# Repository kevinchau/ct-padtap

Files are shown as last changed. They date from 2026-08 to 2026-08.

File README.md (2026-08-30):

# PadTap

Y-harness + board that steals 48 V from the Cybertruck **wireless charger** to run a **Starlink Mini**, without unplugging the pad.

The charger and the key-card reader are the same module. A 1:1 pass-through keeps NFC, HVAC LIN, and USB alive. The board listens to the on-screen pad toggle (LIN) and switches a 5.5 mm barrel.

This is **not** a Tesla-approved tap. Approved 48 V points are the roof and frunk (400 W). Read [SAFETY.md](SAFETY.md) first.

System

Direct 48 V: Mini sees the Tesla rail (typically 44–50 V). The FET opens at **56.0 V** so Tesla’s 58 V peak never reaches the barrel. Digital fuses trip on **inrush** — **10 Ω NTC** on VIN and an **80 ms FET ramp**. Do not skip the thermistor.

The old 36 V buck build is **deprecated**. It does not fit the 15 mm sled. Archive: [hardware/schematic.md](hardware/schematic.md).

## Connector

C X0648 · Tesla **1042593-03-A**. Wire-to-board, not a 4-pin.

| Side | Part |
| --- | --- |
| Vehicle plug | Sumitomo **6098-5718** grey 12-way female |
| Charger | Sumitomo **6098-6210** DL PCB header |

Y: vehicle 5718 → our 6210 (solder a pigtail, pot it) → 1:1 → our 5718 → charger 6210.

Cavity map

Y-harness

| Pin | Color | Terminal | |
| --- | --- | --- | --- |
| **1** | RD/BU 1.00 | 8240-0213 | 48 V HSD — tap |
| 3 | WH/BU 1.00 | 8240-0213 | USB GND thru — no tap |
| **4** | GN 0.35 | 8240-0215 | LIN in — listen only |
| **9** | BN/BU 1.00 | 8240-0213 | WPC GND — tap |
| 10 | GY 0.35 | 8240-0215 | LIN out to HVAC — **never break** |
| 11 / 12 | PK/WH, BU/WH 0.35 | 8240-0215 | CAN auth — no tap |

Latch up, cavities **1–6 over 7–12**. Empty: 2, 5–8. Crimp **18 AWG** into 0213 (16 AWG is out of spec). Full rules: [hardware/harness.md](hardware/harness.md).

## Board

Direct 48 V (`pio run -e direct`):

Direct schematic

- ESP32-C3 SuperMini, TLIN2029 **RX only** (TX not wired)
- IRL540NPBF 100 V FET, low-side on the barrel sleeve
- LM393 + TL431 OVLO, trips **56.14 V** · VIN sense **215 k / 10 k** into GPIO4 (56 V → 2.49 V)
- Gate: 1 k from GPIO5, 10 k pulldown, 47 k + 1 µF smooth the ramp PWM, 1N4148 for fast turn-off
- Littelfuse **0997003.WXN** MINI 3 A **58 V** in and out — not a 32 V blade
- NTC + 80 ms ramp on the harness, outside the box

```
cd firmware/padtap
pio run -e direct -t upload
pio device monitor -b 115200
```

`mode a` / `b` / `c` / `auto` · `ov reset`

| Mode | |
| --- | --- |
| AUTO | First toggle: latch A if 48 V drops, B if LIN flips |
| A | Follow 48 V |
| B | Follow LIN (expected) |
| C | On whenever the rail is up |

OVLO wins: VIN ≥ 56.0 V → FET off.

## PCB — Rev A.1

**58 × 34 mm**, 2-layer. USB-C on the south window, barrel on the east hole, J1 on the west comb.

PadTap Rev A.1

| Zone | |
| --- | --- |
| West | 48 V island: TVS + Schottky + 10 µF/100 V. 1.6 mm rail to the barrel along the south edge, not under the MCU |
| Buck | XL7015, short SW node, catch diode on that pin only |
| North | OVLO (LM393 + TL431), away from SW |
| LIN | 1 k + 220 pF + PESD. TXD **10 k to 5 V** (internal pulldown would dominate the bus) |
| East | IRLR3110 DPAK, 9 thermal vias on the tab |

Gerbers: [hardware/pcb/reva/PadTap-RevA-gerbers.zip](hardware/pcb/reva/PadTap-RevA-gerbers.zip). Fuses and NTC stay on the harness. Confirm XL7015 pinout before SMT.

## Case

**64 × 40 × 15 mm** PETG, sized to the 58 × 34 mm board. VHB the lid under a console panel. Comb west (at J1), barrel east, USB-C south. Print [hardware/enclosure](hardware/enclosure). Confirm **15 mm** of clearance.

Section

## Buy and install

Order list with links: **[hardware/shop.md](hardware/shop.md)**.

T20 at **5 N·m**. Meter the official Mini PSU: barrel is 5.5 mm, **center +**. First wake without Starlink — key card and Qi must still work — then plug the Mini.

| | |
| --- | --- |
| [hardware/shop.md](hardware/shop.md) | Housings, terminals, 58 V fuses, tools |
| [hardware/harness.md](hardware/harness.md) | Pin rules |
| [hardware/pcb/reva](hardware/pcb/reva) | Rev A Gerbers, BOM, CPL |
| [firmware/padtap](firmware/padtap) | ESP32-C3 |

MIT. 48 V is live. That is on you.

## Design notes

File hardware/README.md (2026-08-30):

# Hardware

See [../README.md](../README.md) for the full design. Drawings: [../docs/diagrams/](../docs/diagrams/).

| Path | What |
| --- | --- |
| `harness.md` | Y-harness, connector hunt, pass-through rules |
| `schematic-direct.md` | **Direct 48 V** — the build |
| `schematic.md` | Deprecated 36 V buck archive |
| `bom.csv` | Order list (`rev` = all / direct). `buck` rows are deprecated |
| `pcb/reva/` | **Rev A.1** 58×34 mm Gerbers, JLCPCB BOM/CPL |

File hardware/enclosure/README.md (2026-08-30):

# Under-panel sled

Two-piece PETG, **64 × 40 × 15 mm**, sized to the Rev A.1 board (58 × 34 mm). VHB the lid to the underside of a console panel.

Print `padtap_case.scad` if you have OpenSCAD. `generate_stl.py` emits compact ASCII STLs with the same openings.

| File | |
| --- | --- |
| `padtap_case.scad` | Source. `PART="base"` / `"lid"` / `"preview"` |
| `padtap_base.stl` | Body, openings, bosses |
| `padtap_lid.stl` | Mount face (print this side on the bed) |

## Openings

| Face | Feature | Size |
| --- | --- | --- |
| West | Cable comb, 3 U-slots | 4.0 mm, lines up with J1 VIN / GND / LIN |
| East | Barrel | Ø 8.2 mm at board y = 22.5, center 6 mm above floor |
| South | USB-C | 9.6 × 3.6 mm, centred on board x = 30 |
| Lid | LED membranes | 2× Ø 2.8 mm over the 0805s |
| Lid, bed face | VHB pockets | 4× 10 mm square |

Bosses match the PCB holes at (3, 3), (55, 3), (3, 31), (55, 31).

## Height

Assembled drop **15 mm**. Internal 12.1 mm — enough for the DPAK FET, ESP32-C3-MINI-1, and XL7015. Direct 48 V only.

Fuses and the 10 Ω NTC stay on the harness.

## Print

- PETG. Not PLA.
- 0.2 mm layers, 4 perimeters, 30 % gyroid, 250 / 80 °C.
- Base: floor down. No supports.
- Lid: **VHB face on the bed**, lip up.
- 4× M2.5 × 6 mm into heat-set inserts.

Confirm 15 mm of clearance under the panel before you glue.

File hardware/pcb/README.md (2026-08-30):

# PCB

[**Rev A.1 — Direct 48 V**](reva/) — **58 × 34 mm**, 2-layer.

- [`reva/PadTap-RevA-gerbers.zip`](reva/PadTap-RevA-gerbers.zip) → JLCPCB
- [`reva/pcb-top.svg`](reva/pcb-top.svg)
- `python3 reva/generate.py` regenerates

Sits on the sled floor against the south wall. J1 at the comb. Fuses and NTC are not on this board.

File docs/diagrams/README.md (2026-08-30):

# Drawings

SVGs for the README. No concept photos.

```
python3 generate.py
```

| File | |
| --- | --- |
| `system-direct.svg` | Block diagram |
| `schematic-direct.svg` | Controller |
| `pin-map.svg` | X0648 cavity map, latch up |
| `harness.svg` | Vehicle 5718 → 6210 → 5718 → charger |
| `mating.svg` | 5718 onto 6210 |
| `ovlo.svg` | 56.14 V trip |
| `enclosure-iso.svg` / `enclosure-section.svg` / `enclosure-pack-*.svg` | 64 × 40 × 15 mm sled |
| `pcb-top.svg` | Rev A.1 board, 58 × 34 mm |

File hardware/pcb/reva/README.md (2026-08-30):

# PadTap Direct 48 V — Rev A.1

**58 × 34 mm**, 2-layer, 1.6 mm FR4. ~45 % of the sled cavity. Sits on the floor against the south wall.

Top

| | |
| --- | --- |
| West | J1 VIN / GND / LIN — 18 AWG, ~40 mm pigtail to the comb |
| East | J2 barrel through the sled hole, center + |
| South | USB-C through the window |
| 48 V | West island: TVS + Schottky + 10 µF/100 V. 1.6 mm rail to the barrel along the **south**, not under the MCU |
| SW | XL7015 pin 2 to L1, catch diode on that node only |
| OVLO | North, away from SW. LM393 OC on nGATE |
| Q1 | IRLR3110 DPAK, 9 thermal vias on the tab, source to GND pour |
| LIN | 1 k series + 220 pF + PESD. TXD **10 k to 5 V** (internal pulldown would dominate the bus). RXD 4.7 k to 3V3 |

Fuses and the NTC stay on the harness.

## Order

[`PadTap-RevA-gerbers.zip`](PadTap-RevA-gerbers.zip) → JLCPCB, 2-layer, 1.6 mm, black, HASL. SMT optional: `bom-jlc.csv` + `cpl-jlc.csv`. Confirm LCSC C-numbers.

Place the board so USB-C (30 mm from the west edge) lines up with the 9.6 mm window (outer x = 72).

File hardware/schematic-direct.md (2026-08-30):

# PadTap Direct 48 V

Switched pass-through. No 36 V buck. Starlink Mini sees the Cybertruck rail (typically 44–50 V).

Tesla’s published accessory range is **28 V min / 44–50 V nominal / 58 V max**. Mini is printed **12–48 V**, but the input stage is a 48 V-class converter: Infineon **BSZ146N10LS5** 100 V FETs and a **60 V TVS** across the barrel (clamps ~66–73 V). That hardware will take **~56 V**. Tesla’s 58 V peak is the gap — we disconnect at **56.0 V** instead of converting.

Double-converting (our buck, then Mini’s buck) wastes 4–8 W at cruise. Direct FET loss at 40 W / 48 V is ~0.2 W.

```
VIN_48 ── MINI 3 A 58 V ── NTC 10 Ω ── Schottky SS510 ──┬── SMBJ58A ── GND
                                      │
                                      ├── 5 V buck (7–60 V) ── ESP32-C3 + TLIN2029 VSUP
                                      │
                                      ├── 215 k / 10 k ── ADC GPIO4 + 3.3 V zener
                                      │         │
                                      │         └── 215 k / 10 k ── LM393 IN−
                                      │                              IN+ = 2.495 V (TL431)
                                      │                              OC output ── FET gate
                                      │
                                      └── F2 3 A ── barrel center +
                                                    barrel sleeve ── Q1 drain (IRL540NPBF, 100 V)
                                                                     Q1 source ── GND
                                                                     Q1 gate ← GPIO5 + LM393 OC
```

Low-side switch on the Mini return, same as the 36 V build. Do **not** low-side the WPC ground.

Tesla 48 V **digital fuses** trip on capacitor inrush. The NTC (VIN, on the harness) is what stops a buck from killing the channel — same as a frunk 48 V tap. The 80 ms FET ramp is what stops Mini’s input caps from doing it when the pad toggle arms the output. The NTC is already warm by then (ESP32 is up) so it cannot save Mini turn-on.

## Why 56.0 V, not 58 V

| Limit | V | Source |
| --- | --- | --- |
| Mini printed max | 48 | Spec sheet next to the barrel |
| Mini hardware ceiling | ~56–60 | 100 V input FETs, 60 V TVS |
| Direct OVLO trip | **56.0** | LM393 + firmware latch |
| Direct OVLO clear | 54.0 | Hysteresis |
| Tesla accessory max | 58 | DIY 48 V power-feed document |

If the LV bus ever sits at 58 V, Direct turns Starlink off. That is rare (nominal 44–50 V).

Do **not** put a 54 V TVS across the barrel. Tesla is allowed to run at 50 V; a 54 V clamp would dump the truck’s rail into the diode. Disconnect, don’t clamp.

## OVLO (hardware)

LM393, 5 V VCC, open-collector to the FET gate.

- IN+ = TL431 2.495 V
- IN− = VIN × 10 k / (215 k + 10 k)
- Trip: 2.495 × 225 / 10 = **56.14 V** (215 k 1 %)
- When VIN > 56 V, OC conducts, gate = 0, FET off — even if the ESP32 is wedged
- 1 k between GPIO5 and the OC node so a fight is 3.3 mA, not 33 mA
- After the OC node: 47 k series + 1 µF gate–source smooth the 20 kHz ramp PWM into a gate ramp; 1N4148 across the 47 k dumps the gate fast when the OC (or GPIO) falls

Firmware is the second gate: latches `ov` at 56.0 V, clears at 54.0 V, serial `ov reset` to force. Its VSENSE divider is **215 k / 10 k** (same values as the comparator's) — a 100 k / 10 k divider would clip at the 3.3 V zener around 36 V and the firmware latch could never see 56 V.

## Nets

| Net | From | To |
| --- | --- | --- |
| VIN_48 | Y-harness 48 V+ via 3 A fuse | NTC 10 Ω → Schottky → SMBJ58A → 5 V buck + barrel center via F2 |
| GND | Y-harness GND | Board GND, Q1 source |
| LIN_BUS | Y-harness LIN (parallel) | TLIN2029 LIN pin |
| LIN_RX | TLIN2029 RXD | ESP32 GPIO20 |
| V5 | 5 V buck | ESP32 5V, TLIN VSUP, LM393 VCC, TL431 bias |
| VOUT+ | F2 3 A after VIN | Barrel center + (unswitched) |
| VOUT− | Barrel sleeve | Q1 drain (switched low-side) |
| VSENSE | 215 k / 10 k on VIN_48 (56 V → 2.49 V) | ESP32 ADC, 3.3 V zener backstop |
| nGATE | ESP32 GPIO5 + 1 k, 10 k pulldown, LM393 OC | 47 k + 1 µF RC → IRL540NPBF gate, 1N4148 across the 47 k for fast turn-off |

## GPIO

Same map as the 36 V build.

| Pin | Function |
| --- | --- |
| GPIO20 | UART RX (LIN) |
| GPIO5 | FET gate (1 k) |
| GPIO4 | ADC VIN_48 |
| GPIO6 | Amber LED, rail present |
| GPIO7 | Green LED, output armed |

## Protection

- Littelfuse **0997003.WXN** MINI 3 A **58 V** on VIN_48
- Same 3 A 58 V on barrel (Starlink 60 W / 48 V ≈ 1.25 A; 60 W / 28 V ≈ 2.1 A)
- SMBJ58A on VIN_48 only
- Series Schottky 100 V 5 A reverse protection
- 3.3 V zener on ADC node (backstop — the 215 k / 10 k divider stays under 2.6 V even at 58 V)
- LM393 OVLO + firmware latch at 56.0 V
- 100 V logic-level FET (**IRL540NPBF**) — FQP13N10L is obsolete; 60 V FQP30N06L is too close to Tesla max

## Current

| Mini load | @ 36 V (buck) | @ 48 V (direct) |
| --- | --- | --- |
| 25 W cruise | 0.69 A | 0.52 A |
| 40 W typical | 1.11 A | 0.83 A |
| 60 W peak | 1.67 A | 1.25 A |

3 A fuse still the right ceiling. Tap pigtails are **18 AWG GXL** into 8240-0213 (16 AWG is out of spec).

## Forbidden

| Don’t | Why |
| --- | --- |
| 36 V buck in this build | That’s the other schematic |
| FQP30N06L (60 V) | Tesla max 58 V + Mini input inductance |
| SMBJ40A / 54 V TVS on VOUT | Clamps a legal Tesla rail |
| LM2596 / MP1584 | 5 V buck must be 60 V-in |
| Driving LIN TX | Sniffer only |
| Feeding Mini above 56 V “because the TVS is 60 V” | TVS is a clamp, not an operating point |

Flash the `direct` PlatformIO env.

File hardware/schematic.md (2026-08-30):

# DEPRECATED — Buck 36 V

**Do not build this.** PadTap is Direct 48 V. The 64 × 40 × 15 mm sled cannot fit a 36 V module. Firmware `env:buck` is gone.

Use **[schematic-direct.md](schematic-direct.md)**.

The rest of this page is an archive of the old conservative path (60 V → 36 V module, Mini stays inside the printed 12–48 V rating).

---

# PadTap controller (archive)

Two builds, one Y-harness, one sled.

| | **Direct 48 V** (default) | **Buck 36 V** (conservative) |
| --- | --- | --- |
| Doc | [schematic-direct.md](schematic-direct.md) | this page |
| Mini sees | Raw Tesla rail, typically 44–50 V | Regulated 36.00 V |
| Extra conversion | None | 60 V → 36 V buck ≤ 12 mm |
| Overvoltage | LM393 + firmware kill FET at **56.0 V** | Buck absorbs Tesla’s 58 V peak |
| Use when | You want the efficiency; Mini hardware takes ~56 V | You want to stay inside the printed 12–48 V rating |

Shared front end: 48 V in (Tesla 28–58 V) → fused → **NTC 10 Ω ICL** → reverse Schottky → TVS.

Tesla 48 V digital fuses trip on buck input-cap inrush. The NTC is not optional on the 36 V build — that is the exact failure of a raw converter on the frunk tap. Direct still needs it for the 5 V MCU buck, plus an 80 ms FET ramp for Mini’s own caps.

- **5 V buck** (7–60 V in): ESP32-C3 + TLIN2029A-Q1 VSUP
- **LIN RX only** — TX pin not wired

## Buck 36 V

48 V in → fused → reverse Schottky → TVS → two bucks.

- **36 V buck** (8–60 V in, 3 A, ≤10 mm tall): Starlink Mini sweet spot. The 12.1 mm Direct sled does **not** fit a 12 mm tower — use a SIP or skip this build.
- **FQP30N06L** low-side switch on Starlink return (36 V, 60 V FET is enough here)

## Nets (buck)

| Net | From | To |
| --- | --- | --- |
| VIN_48 | Y-harness 48 V+ via 3 A fuse | NTC 10 Ω → Schottky → SMBJ58A → both bucks |
| GND | Y-harness GND | Board GND, FET source, barrel sleeve |
| LIN_BUS | Y-harness LIN (parallel) | TLIN2029 LIN pin |
| LIN_RX | TLIN2029 RXD | ESP32 GPIO20 |
| V5 | 5 V buck | ESP32 5V, TLIN VSUP |
| V36 | 36 V buck | Barrel center via FET + 3 A fuse |
| VSENSE | 215 k / 10 k on VIN_48 | ESP32 ADC, 3.3 V zener backstop |
| nGATE | ESP32 GPIO5 + 100 Ω | FET gate, 10 k pulldown |

## GPIO

| Pin | Function |
| --- | --- |
| GPIO20 | UART RX (LIN) |
| GPIO5 | FET gate |
| GPIO4 | ADC VIN_48 |
| GPIO6 | Amber LED, rail present |
| GPIO7 | Green LED, output armed |

## Protection (buck)

- Littelfuse 0997003.WXN MINI 3 A **58 V** on VIN_48 (not a 32 V mini)
- Same 3 A 58 V on V36
- SMBJ58A on VIN_48
- SMBJ40A on V36
- Series Schottky (100 V, 5 A) reverse protection
- 3.3 V zener on ADC node (backstop — 215 k / 10 k keeps 58 V at 2.58 V; the original 100 k / 10 k clipped at the zener near 36 V, blinding the firmware OVLO)

Firmware still runs the 56 V OVLO so a mis-set 36 V pot cannot pass Tesla’s peak.

## Forbidden parts

| Don’t use | Why |
| --- | --- |
| LM2596 | 40 V max input |
| MP1584 | 28 V max input |
| 12 V car-USB adapters | Wrong rail, wrong range |
| Driving LIN TX | We are not a second commander |

## Rev B

`pcb/` is reserved for an LM76003-Q1 + TLIN2029A-Q1 + ESP32-C3 board after the probe log names the LIN PID and the Tesla housing. Direct 48 V Rev B would drop the 36 V buck and keep the OVLO comparator.

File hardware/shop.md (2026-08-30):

# Supply and tool list

US vendors. Prices as of 2026-08-29, they move. Direct 48 V build.

Do **not** buy 32 V mini fuses. Tesla LV is 48 V, allowed to 58 V.

## Connectors

| Item | PN | Qty | Buy | ~$ |
| --- | --- | --- | --- | --- |
| 12-way female, grey | 6098-5718 | 1 (buy 2) | [Nexelec](https://nexelec.com/products/sumitomo-60985718) · [eBay 4-pack](https://www.ebay.com/itm/374601171115) · [AliExpress 10](https://www.aliexpress.com/item/1005008563988761.html) | 4–12 |
| 12-way male PCB header | 6098-6210 | 2 | [Octopart](https://octopart.com/search?q=6098-6210) · [Eleocean](http://www.eleocean.com/productshow.php?cid=25&id=13164) | 3–8 |
| Female terminal 0.75–1.25 mm² | 8240-0213 | 10 | [Connector ID (singles)](https://www.connectorid.com/products/sumitomo-8240-0213) · [Nexelec MOQ 200](https://nexelec.com/products/sumitomo-82400213) · [Auto-Click](https://www.auto-click.co.uk/8240-0213) | 0.62 ea |
| Female terminal 0.3–0.5 mm² | 8240-0215 | 10 | [Nexelec](https://nexelec.com/products/sumitomo-82400215) | 0.49 ea |

5718 plugs into the charger. 6210 is a through-hole header — solder a pigtail, pot it, vehicle 5718 plugs onto that. Confirm TPA in the 5718 bag.

## Wire and insulation

| Item | PN | Qty | Buy | ~$ |
| --- | --- | --- | --- | --- |
| 18 AWG GXL red | WL18-2 | 10 ft | [Waytek](https://www.waytekwire.com/search?query=WL18-2) | 0.25/ft |
| 18 AWG GXL black | WL18-0 | 10 ft | [Waytek](https://www.waytekwire.com/search?query=WL18-0) | 0.25/ft |
| 22 AWG GXL green | GXL-22 | 5 ft | [Waytek GXL catalog](https://www.waytekwire.com/catalog/wire-and-cable/automotive-cross-link-wire) | 0.20/ft |
| Adhesive-lined 3:1 shrink kit | 3:1 dual-wall | 1 | [Amazon](https://www.amazon.com/s?k=adhesive+lined+heat+shrink+3%3A1+kit) | 15 |
| PET cloth harness tape | tesa 51036 19 mm | 1 | [Amazon](https://www.amazon.com/dp/B0DF8NPC66) | 12 |

Do not crimp 16 AWG into 8240-0213 (max 1.25 mm²).

## Fuses — 58 V

| Item | PN | Qty | Buy | ~$ |
| --- | --- | --- | --- | --- |
| MINI 3 A 58 V | 0997003.WXN | 5 | [Digi-Key](https://www.digikey.com/en/products/detail/littelfuse-inc/0997003-WXN/701055) | 1 ea |
| MINI in-line holder 16 ga | LPM-04B class | 2 | [Waytek](https://www.waytekwire.com/product/optifuse-lpm-04b-1-16r-mini-in-line-fuse-holder) | 4 ea |

A 32 V mini (the violet 3 A at AutoZone) is the wrong part.

## Board

| Item | PN | Qty | Buy | ~$ |
| --- | --- | --- | --- | --- |
| ESP32-C3 SuperMini 3-pack | ESP32-C3-FH4 | 1 pack | [Amazon](https://www.amazon.com/dp/B0F12JS872) | 13 |
| LIN transceiver | TLIN2029DRQ1 | 2 | [Digi-Key](https://www.digikey.com/en/products/detail/texas-instruments/TLIN2029DRQ1/8322880) · [Mouser](https://www.mouser.com/ProductDetail/Texas-Instruments/TLIN2029DRQ1) | 2 |
| 5–80 V → 5 V buck | XL7015 | 2 | [Amazon](https://www.amazon.com/dp/B0FCXYMQ1S) | 8 |
| NTC 10 Ω 3.7 A | B57237S0100M000 | 2 | [Digi-Key](https://www.digikey.com/en/products/detail/tdk-epcos/B57237S0100M000/652130) | 1.44 |
| TVS 58 V | SMBJ58A | 5 | [Digi-Key](https://www.digikey.com/en/products/detail/littelfuse-inc/SMBJ58A/276411) | 0.50 |
| Schottky 100 V 5 A | SS510 / SS5P10 | 5 | [Digi-Key search](https://www.digikey.com/en/products/filter/diodes-rectifiers-single?keywords=SS510) | 0.60 |
| Starlink Mini DC cable 5.5×2.1 | DC5521 | 1 | [Amazon](https://www.amazon.com/dp/B0DLL79FJY) | 14 |
| 1N4148 (gate diode) | 1N4148TR | 10 | [Digi-Key](https://www.digikey.com/en/products/detail/onsemi/1N4148TR/458966) | 0.10 |
| 3.3 V zener | MMSZ5226BT1G | 5 | [Digi-Key](https://www.digikey.com/en/products/detail/on-semiconductor/MMSZ5226BT1G/919344) | 0.20 |
| N-FET 100 V logic TO-220 | IRL540NPBF | 2 | [Digi-Key](https://www.digikey.com/en/products/detail/infineon-technologies/IRL540NPBF/812000) | 2.47 |
| Dual comparator | LM393P | 2 | [Digi-Key](https://www.digikey.com/en/products/detail/texas-instruments/LM393P/277092) | 0.50 |
| 2.495 V ref | TL431CP | 2 | [Digi-Key](https://www.digikey.com/en/products/detail/texas-instruments/TL431CP/276496) | 0.50 |
| 215 k 1% 0805 | — | 10 | [Digi-Key](https://www.digikey.com/en/products/filter/chip-resistor-surface-mount?keywords=215k%200805%201%25) | 1 |

FQP13N10L is obsolete. IRL540NPBF is the 100 V logic-level stand-in. Lay the TO-220 flat.

## Case

| Item | PN | Qty | Buy | ~$ |
| --- | --- | --- | --- | --- |
| PETG black 1.75 mm | — | 1 kg (~20 g used) | [Amazon](https://www.amazon.com/s?k=PETG+filament+black+1.75mm) | 20 |
| M2.5 heat-set + 6 mm screws | M2.5 | 1 kit | [Amazon](https://www.amazon.com/s?k=M2.5+heat+set+inserts+kit) | 10 |
| 3M VHB 5952 1/2 in | 5952 | 1 roll | [Amazon](https://www.amazon.com/s?k=3M+VHB+5952+1%2F2+inch) | 18 |

## Tools

| Item | PN | Buy | ~$ |
| --- | --- | --- | --- |
| Open-barrel crimper 14–24 AWG | IWISS IWC-1424A | [Amazon](https://www.amazon.com/dp/B096JS87R8) | 35 |
| T20 Torx | Klein 19543 | [Amazon](https://www.amazon.com/dp/B00093DYRO) | 12 |
| Torque driver 1–6 N·m | 1/4 in | [Amazon](https://www.amazon.com/s?k=1%2F4+inch+torque+screwdriver+6+Nm) | 40 |
| Nylon trim pry set | — | [Amazon](https://www.amazon.com/s?k=automotive+trim+removal+tool+set+nylon) | 12 |
| DMM 60 V CAT III | Klein MM400 | [Amazon](https://www.amazon.com/s?k=Klein+MM400) | 50 |
| Soldering iron | TS101 | [Amazon](https://www.amazon.com/s?k=TS101+soldering+iron) | 40 |
| Heat gun | — | [Amazon](https://www.amazon.com/s?k=heat+gun+adhesive+shrink) | 25 |
| Terminal pick | — | [Amazon](https://www.amazon.com/s?k=automotive+terminal+release+tool+pick) | 10 |
| OEM TS 1.5 mm die (optional) | Rennsteig 624 1686 3 012 RT | [Rennsteig](https://www.rennsteig.us/products/crimping-tools/general-stamped-and-formed-contacts/1628-crimp-die-set-for-sumitomo-ts-series-1-5-mm-060-terminals) · [EFI](https://www.eficonnection.com/home/product/rennsteig-crimp-die-set-624-1686-3-012rt) | 300 + frame |
| Logic analyzer (optional) | 8-ch 24 MHz | [Amazon](https://www.amazon.com/s?k=8+channel+logic+analyzer+24MHz+USB) | 15 |
| Hot-glue / DP100 | pot 6210 | [Amazon](https://www.amazon.com/s?k=hot+glue+gun+kit) | 10 |

Do not use an SN-28B on 8240-0213. IWC-1424A or the Rennsteig die. Pull-test every crimp.

## Order in three carts

1. **Nexelec / Connector ID / Octopart** — 5718, 6210, terminals.
2. **Digi-Key** — NTC, TLIN2029, SMBJ58A, IRL540N, LM393, TL431, 58 V fuses, passives.
3. **Amazon + Waytek** — ESP32, XL7015, Starlink cable, crimper, T20, tape, GXL, VHB, PETG.

One-off parts ~$90–120. Tools ~$150 if you don't already have a DMM and iron. Skip the $300 Rennsteig unless you are making more than one Y.

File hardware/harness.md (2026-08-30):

# Y-harness

Sits between the Cybertruck center-console wireless charger (Tesla PN **1877045**, connector **C X0648**) and the vehicle plug.

Sources:
- [Electrical Reference sheet 46](https://service.tesla.com/docs/Cybertruck/ElectricalReference/prog-242/interactive/pdf/console_phone_and_usb_charging_print.pdf)
- [X0648 connector page](https://service.tesla.com/docs/Cybertruck/ElectricalReference/prog-242/connector/x0648/) — Tesla PN **1042593-03-A**

```
VEHICLE 5718 ──► [our 6210 male]─┬─ 1:1 ─► [our 5718 female] ──► CHARGER 6210
                                 │
                                 ├─ pin 1  RD/BU  18 AWG  ─► PadTap VIN  (3 A + NTC)
                                 ├─ pin 9  BN/BU  18 AWG  ─► PadTap GND
                                 └─ pin 4  GN     22 AWG  ─► TLIN2029 RX only
```

## Plastics

This is **wire-to-board**, not a sealed 4-pin GT150.

| Side | Sumitomo | Tesla | What it is |
| --- | --- | --- | --- |
| Vehicle harness (unplugs from the charger) | **6098-5718** grey 12-way **female** | 1042593-03-A / X0648 | TS/DL 1.5 mm (060), unsealed |
| Charger module | **6098-6210** 12-way **male** | on 1877045 | DL series PCB header, grey, TH, horizontal mate |

5718 plugs onto 6210. Confirmed: [Nexelec](https://nexelec.com/products/sumitomo-60985718) lists 6210 as the mate; Sumitomo’s PCB catalogue lists 6210 as a 12-way DL header.

**Y-harness buy list**

1. **6098-5718** female — plugs into the charger. Crimp terminals below.
2. **6098-6210** male PCB header — the vehicle 5718 plugs onto this. 6210 is a through-hole header, not a wire housing. Solder a pigtail to the pins (or a 25 mm breakout) and strain-relief / pot it. Do not expect a free-hanging male 6210.

Mating face of **6098-5718**, latch up (Tesla X0648 drawing):

```
        [ latch / CPA ]
   1    2    3    4    5    6
   7    8    9   10   11   12
```

1 and 7 are on the latch-left. Empty: 2, 5, 6, 7, 8. Tap 1 (top-left), 9 (under 3), 4 (top row, fourth).

## Terminals (into 5718 only)

Tesla cavity table, X0648:

| Cavity | Terminal | Size | Color | mm² | Dest | Tap? |
| --- | --- | --- | --- | --- | --- | --- |
| **1** | 8240-0213 | 1.5×0.64 F | **RD/BU** | 1.00 | X0644-20 (Console VBATT) | **Yes** |
| 2 | unused | | | | | empty |
| **3** | 8240-0213 | 1.5×0.64 F | WH/BU | 1.00 | X0644-1 | Pass-through (USB GND) |
| **4** | 8240-0215 | 1.5×0.64 F | **GN** | 0.35 | X0944M-5 (LIN in) | **Listen only** |
| 5–8 | unused | | | | | empty |
| **9** | 8240-0213 | 1.5×0.64 F | BN/BU | 1.00 | X0944M-6 (WPC GND) | **Yes** |
| **10** | 8240-0215 | 1.5×0.64 F | GY | 0.35 | X0644-16 (LIN out / HVAC) | **Never break** |
| **11** | 8240-0215 | 1.5×0.64 F | PK/WH | 0.35 | X0944M-11 CANH | No tap |
| **12** | 8240-0215 | 1.5×0.64 F | BU/WH | 0.35 | X0944M-12 CANL | No tap |

**8240-0213** — female, tin, TS 1.5 mm, **0.75–1.25 mm²** (16–18 AWG), insulation 1.4–2.3 mm. Use on cavities 1, 3, 9. Tesla’s 1.00 mm² sits in the middle. **Do not crimp 16 AWG GXL** (1.31 mm², fat insulation) — it is out of spec. Tap pigtails: **18 AWG GXL** or 1.00 mm² FLRY.

**8240-0215** — female, tin, TS 1.5 mm, **0.3–0.5 mm²**, insulation 1.1–1.7 mm. Use on 4, 10, 11, 12. LIN tap: **22 AWG**.

Male tabs are part of the 6210 header. No crimp males unless you change architecture.

Crimp: open-barrel Sumitomo TS 1.5 mm die (Rennsteig lists 8240-0213). A random SN-28B will smash these.

## Why a Y, not an unplug

Unplugging X0648 kills NFC (CAN 11/12), HVAC switchpack LIN (pin 10), and USB pass-through (1/3).

Tesla R&R: disconnect, harness clip, T20 ×4 at **5 N·m**.

## Power

Pin 1 is Right Controller high-side **X0034-91** `WIRELESS_PHONE_CHARGER_AND_VCUSB`, shared with USB. Pad toggle is LIN (`LIN_INDUCTIVE_CHARGER` on pin 10). Mode B expected. NTC + 80 ms ramp on the tap.

## Rules

- 1:1 on cavities 1, 3, 4, 9, 10, 11, 12. Leave 2, 5–8 empty.
- Tap only **1, 9, 4**. Pin 4 parallel, no extra pull-up, no TX.
- Never open 10 or 11/12. Do not use pin 3 as PadTap ground.
- Adhesive shrink, cloth tape, strain-relief so seat travel cannot yank 5718 off 6210.

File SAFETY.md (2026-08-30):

# Safety

Cybertruck low voltage is **48 V** and Tesla says to assume every LV wire and connector is **always energized**, even when the truck is “off.”

- Eye protection. No jewelry. Insulated probes.
- 48 V arcs. A short across a blue connector can weld a probe tip and pop a body-controller fuse. Some of those fuses feed more than a phone pad.
- Do **not** unplug the wireless charger as a “test.” It is the key-card NFC reader.
- Do **not** inject power into Tesla (no backfeed from a bench supply into VIN_48).
- Do **not** drive LIN TX until you have captured the bus and know you are not colliding with the commander.
- Fuse the tap at **3 A**. If Tesla’s upstream fuse is smaller than Starlink + pad, stop and use the 400 W roof/frunk feed instead.
- Tesla 48 V is **digitally fused**. Buck converters and Mini input caps look like a short for microseconds and the channel goes dark. Put a **10 Ω ≥3 A NTC ICL on VIN** (harness, next to the fuse — this is what stops a frunk 48 V tap from erroring). Firmware ramps the load FET over 80 ms. Do not skip either.
- Tesla max is **58 V**. Mini printed max is **48 V**; Mini hardware is ~**56 V**. Direct 48 V **must** include the 56.0 V OVLO (LM393 + firmware). Never defeat it. Never clamp the Tesla rail with a 54 V TVS.
- First power-up of the Mini happens **after** NFC and Qi are confirmed still working.
- This is not a Tesla-approved accessory point. Warranty, fire, and brick risk are yours.

Tesla-approved alternative: [Connecting Accessories to the 48V Power Feeds](https://service.tesla.com/docs/Public/diy/cybertruck/en_us/GUID-EC88B024-50C5-4B34-B716-FDED8CF3FBE0.html) — roof and frunk, 400 W each.

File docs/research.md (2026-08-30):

# Research notes

Compiled 2026-08-29 for kevinchau/ct-padtap. Direct-48 V path added 2026-08-29.

## Cybertruck 48 V

Tesla public DIY: [Connecting Accessories to the 48V Power Feeds](https://service.tesla.com/docs/Public/diy/cybertruck/en_us/GUID-EC88B024-50C5-4B34-B716-FDED8CF3FBE0.html)

- Only approved taps: roof 400 W, powered frunk 400 W
- Voltage: **28 V min, 44–50 V nominal, 58 V max**
- Three wires: red/blue = 48 V+, green = LIN, black/blue (roof) or brown/blue (frunk) = GND
- 48 V connectors are **blue**; 48 V wires have **blue tape** ([owner manual](https://www.tesla.com/ownersmanual/cybertruck/en_us/GUID-2233D4D1-D4E5-4897-9A41-DE8593381CAA.html))
- LV is assumed **always energized**
- Enable from Controls → Outlets & Mods. Keep Outlets On for after-exit power.

Real-world bus sits in the nominal band. 58 V is the design maximum of the HV→LV converter, not the everyday voltage. Direct 48 V still treats 58 V as a disconnect, not an operating point.

Tesla: the 400 W feeds “stop providing power when current that exceeds the listed specifications is detected” and reset from Controls → Outlets & Mods → Reset. Those are **solid-state / digital fuses**, not slow blade fuses. The wireless-pad circuit is a smaller body-controller channel with the same kind of protection.

### Inrush / NTC

A buck converter’s input capacitors look like a short for microseconds. On Cybertruck 48 V that spike trips the digital fuse even when steady-state watts are fine — this is the known failure of a raw 48 V → 12 V module on the frunk tap. The fix that works in the truck is an **NTC inrush current limiter** in series with VIN (10 Ω cold, ≥3 A, e.g. EPCOS B57237S0100M000 / MF72-10D13). After it warms it drops to a few tenths of an ohm.

PadTap:

- **NTC on VIN**, after F1, on the harness next to the fuse holders (the disc does not fit the 12.1 mm sled). Covers the 5 V MCU buck and the optional 36 V buck.
- **80 ms FET ramp** (firmware PWM + 47 k / 1 µF on the gate) so Starlink Mini’s own input caps don’t dump the same spike when the pad toggle arms the output. An NTC on VIN is already warm by then (ESP32 is up) so it cannot save the Mini turn-on — the ramp has to.

Do not substitute a signal thermistor (10 k NTC). It has to be a power ICL.

## Wireless charger

Tesla Electrical Reference, **Console – Phone and USB Charging**, sheet 46, prog-242 rev 1.11:

https://service.tesla.com/docs/Cybertruck/ElectricalReference/prog-242/interactive/pdf/console_phone_and_usb_charging_print.pdf

Module: **Wireless Phone Charger + NFC Reader**, connector **C X0648**. Tesla housing PN **1042593-03-A**.

Plastics (confirmed against the X0648 connector page and the user’s identification):

- Vehicle plug: Sumitomo **6098-5718** grey 12-way female, TS/DL 1.5 mm unsealed
- Charger: Sumitomo **6098-6210** 12-way male DL PCB header (wire-to-board)
- Female terminals: **8240-0213** (0.75–1.25 mm²) on 1/3/9, **8240-0215** (0.3–0.5 mm²) on 4/10/11/12
- Cavity table: 1 RD/BU 1.00, 3 WH/BU 1.00, 4 GN 0.35, 9 BN/BU 1.00, 10 GY 0.35, 11 PK/WH 0.35, 12 BU/WH 0.35. Unused: 2, 5, 6, 7, 8

48 V is a **Right Controller high-side drive** X0034-91, net `WIRELESS_PHONE_CHARGER_AND_VCUSB` (RD/BU 1.00 mm² into pin 1). Shared with the USB hub — the pad toggle is not going to drop this rail. LIN in on pin 4 (GN), LIN out on pin 10 (GY, `LIN_INDUCTIVE_CHARGER`) to the HVAC switchpack / touchpad. CAN auth on 11/12 to the Left Controller.

Do not put Tesla’s PDF in a public fork. Transcribe pin facts; do not republish the sheet.

Tesla R&R: [Wireless Charger - Center Console](https://service.tesla.com/docs/Cybertruck/ServiceManual/en-us/GUID-8B81665F-D4DC-4DED-B787-45A957056FF9.html) — one electrical connector, harness clip, T20 ×4 at 5 N·m.

- Tesla PN **1877045-00-A / 00-C** Gen 5.0, dual 15 W Qi, center console
- R&R: [GUID-8B81665F-D4DC-4DED-B787-45A957056FF9](https://service.tesla.com/docs/Cybertruck/ServiceManual/en-us/GUID-8B81665F-D4DC-4DED-B787-45A957056FF9.html) — connector + clip, T20 ×4, 5 N·m
- Same location as **key-card NFC**. Unplug → Service Mode error, NFC dead, sometimes ambient light dead ([CTOC](https://www.cybertruckownersclub.com/forum/threads/disable-wireless-charging-pad.15032/page-2), Facebook: “the plug has 4 pins”)
- Pads feel warm even empty (always drawing)
- Software disable (Holiday 2025): Controls → Outlets & Mods → Wireless Phone Charging Pads ([owner manual](https://www.tesla.com/ownersmanual/cybertruck/en_us/GUID-7B00E438-94C4-4B66-BBEB-0C39C70777DC.html))

## LIN

Model Y WPC teardown uses **NXP TJA1021** LIN PHY ([ChargerLAB](https://www.chargerlab.com/teardown-of-tesla-model-y-15w-wireless-charging-module-2)). Cybertruck 48 V accessories (factory lightbar) are 48 V + LIN; community intercepts use ESP32 + LIN transceiver with TX careful / listen. LIN recessive is ~12 V even on a 48 V vehicle.

Working assumption: screen toggle is a **LIN command**, not a 48 V cut — otherwise NFC dies. Firmware auto-detects the other case.

## Starlink Mini

[Spec sheet](https://starlink.com/public-files/specification_sheet_mini.pdf): **12–48 V DC, 60 W**, 25–40 W average. USB-C PD path is 100 W / 20 V / 5 A with Starlink’s cable.

Barrel: 5.5 mm OD. Spec drawing shows 2.5 mm pin; field reports 2.1 mm plugs working. **Confirm polarity on the official PSU** (center + expected).

### Hardware above 48 V

Printed rating is 48 V. Teardown of the Mini input ([DIY Solar #86410](https://diysolarforum.com/threads/starlink-mini-dc-power-consumption.86410/), PCB photo [Oleg Kutkov](https://x.com/olegkutkov/status/1817940568304971945)):

- Input DC-DC FETs: Infineon **BSZ146N10LS5**, 100 V
- TVS across the barrel: **60 V** class, clamps ~66–73 V
- Reverse-protect back-to-back MOSFETs on the input
- Controller IC unpublished; 48 V-class parts imply ~60 V abs max

That is why Direct 48 V is viable on a Cybertruck: nominal 44–50 V is inside both the printed spec and the silicon. The only conflict is Tesla’s **58 V** design max vs Mini’s **~56 V** comfortable hardware ceiling. PadTap Direct **opens the FET at 56.0 V** (LM393 + firmware latch, clears at 54.0 V). We do not ride the Mini’s TVS.

CTOC: people have run Mini on the **roof/frunk 48 V feeds** successfully at nominal voltage. Direct on the pad tap is the same rail, plus a disconnect for the 58 V tail.

The 36 V buck path is **deprecated** and does not fit the 15 mm sled.

## Wiring guide

Interactive connector/pinout/wire-color diagrams: **Service Mode Plus → Low Voltage → Wiring Service Diagram** (2025+). service.tesla.com Electrical Reference is the same data, login-walled.

## Not this project

HV “Inductive Charger” headers on the traction battery are for vehicle wireless charging (cancelled for CT). Unrelated to the phone pad.

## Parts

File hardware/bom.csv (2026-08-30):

group | item | pn | qty | source | cost | why | rev
Harness | Tesla WPC donor (optional harvest) | 1877045-00-C | 1 | eBay / Tesla parts | $80-180 | Only if you would rather steal a 6210 header than solder one | all
Harness | Sumitomo 12-way female grey | 6098-5718 | 1 | eBay / Nexelec / AliExpress | $8-12 | Plugs into the charger 6210. Tesla 1042593-03-A / X0648 | all
Harness | Sumitomo 12-way male PCB header | 6098-6210 | 1 | Eleocean / auto-electron | $3-8 | Vehicle 5718 plugs onto this. DL TH header — solder a pigtail do not expect a wire housing | all
Harness | Female terminal 1.00 mm2 | 8240-0213 | 10 | Nexelec / AliExpress | $5 | TS 1.5mm 0.75-1.25 mm2 tin. Cavities 1 3 9. Not for 16 AWG GXL | all
Harness | Female terminal 0.35 mm2 | 8240-0215 | 10 | TTI / AliExpress | $5 | TS 1.5mm 0.3-0.5 mm2 tin. Cavities 4 10 11 12 | all
Harness | 18 AWG GXL red+black | GXL-18 | 3m | Waytek | $10 | Power tap into 8240-0213 (16 AWG is out of spec) | all
Harness | 22 AWG GXL green | GXL-22 | 1m | Waytek | $6 | LIN listen on pin 4 into 8240-0215 | all
Harness | Adhesive heat-shrink + cloth tape | 3:1 dual-wall | 1 kit | Amazon | $14 | Tesla DIY insulation spec | all
Board | ESP32-C3 SuperMini | ESP32-C3-FH4 | 1 | LCSC / Amazon | $8 | MCU | all
Board | LIN transceiver | TLIN2029A-Q1 | 1 | Mouser | $6 | Listen-only PHY | all
Board | 7-60 V to 5 V 2 A buck | XL7015 class | 1 | Amazon | $8 | MCU rail — not MP1584 | all
Board | MINI fuse 3 A 58 V + in-line holder | 0997003.WXN | 5 | Digi-Key / Waytek | $10 | Do not use 32 V mini — Tesla LV is 48 V allowed to 58 V | all
Board | NTC inrush limiter 10 ohm ≥3 A | B57237S0100M000 / MF72-10D13 | 1 | Digi-Key / Amazon | $2 | Tesla digital fuses trip on buck inrush — series on VIN after F1 on the harness not in the sled | all
Board | Gate soft-start 47k + 1uF + 1N4148 | 47k+1uF+1N4148 | 1 | Digi-Key | $1 | 80 ms FET ramp so Mini input caps do not dump the pad circuit | all
Board | TVS 58 V | SMBJ58A | 1 | Digi-Key | $1 | VIN clamp | all
Board | Schottky 100 V 5 A | SS510 | 1 | Digi-Key | $1 | Reverse protect | all
Board | Barrel 5.5x2.1 center + | DC5521 male | 1 | Amazon / Starlink DC extension | $9 | Confirm polarity on official PSU | all
Board | Divider 215k/10k 1% | 0805 | 1 | Digi-Key | $1 | VIN sense into ESP32 ADC — 56 V → 2.49 V (100k/10k would clip at the zener) | all
Board | 3.3 V zener + gate R | MMSZ5226B | 1 | Digi-Key | $2 | ADC clamp | all
Board | LEDs amber/green | 3mm | 2 | Digi-Key | $1 | Status through lid membranes | all
Direct 48 V | Logic-level N-FET 100 V | IRL540NPBF | 1 | Digi-Key | $3 | FQP13N10L is obsolete. 100 V logic-level low-side. Lay TO-220 flat | direct
Direct 48 V | LM393 dual comparator | LM393P | 1 | Digi-Key | $1 | Hardware OVLO open-collector on FET gate | direct
Direct 48 V | TL431 2.495 V ref | TL431ACP | 1 | Digi-Key | $1 | LM393 IN+ reference | direct
Direct 48 V | OVLO divider 215k / 10k 1% | 215k+10k | 1 | Digi-Key | $1 | Trip 2.495 × 225/10 = 56.14 V | direct
Buck 36 V | Low-profile 60 V 3 A buck set to 36 V | 60Vin 36Vout 3A slim ≤10mm | 1 | Amazon / LCSC | $12 | Direct sled is 12.1 mm inside — skip 5 A tower | buck
Buck 36 V | Logic-level N-FET 60 V | FQP30N06L | 1 | Digi-Key 671-FQP30N06L | $2 | Low-side Starlink switch on 36 V — lay TO-220 flat | buck
Buck 36 V | TVS 40 V | SMBJ40A | 1 | Digi-Key | $1 | V36 clamp | buck
Case | Printed under-panel sled PETG | hardware/enclosure/ | 1 | Print the STLs / OpenSCAD | ~$2 filament | 64x40x15 mm VHB lid | all
Case | M2.5 x 6 mm + heat-set inserts | M2.5 | 4 | Amazon | $4 | Lid screws into base bosses — 8 mm bottoms out in the 3.8 mm insert pocket | all
Case | 3M VHB 5952 12 mm squares | 5952 | 4 | Amazon | $8 | Lid bed face to panel underside | all
Tools | Torx T20 | T20 | 1 | any | $8 | 5 N·m WPC screws | all
Tools | Plastic pry set | — | 1 | any | $10 | Console panel | all
Tools | DMM 60 V DC | — | 1 | own | own | Pin ID — LV assumed live | all
Tools | Logic analyzer 24 MHz | Saleae or 8-ch | 1 | Amazon | $15 | Optional LIN capture | all

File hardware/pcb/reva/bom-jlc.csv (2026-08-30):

Designator | Comment | LCSC | Qty | Note
U1 | ESP32-C3-MINI-1-N4 | C2919203 | 1 | MCU | antenna north
U2 | XL7015E1 SOP-8 | C142613 | 1 | 5–80 V → 5 V. Pins 1 VIN | 2 SW | 3 GND | 4 FB | 5 COMP | 6 EN | 8 VIN
U3 | AMS1117-3.3 SOT-223 | C6186 | 1 | 5 V → 3.3 V
U4 | TLIN2029DRQ1 SOIC-8 | C582774 | 1 | 1 RXD | 2 EN | 4 TXD | 5 GND | 6 LIN | 7 VSUP
U5 | LM393DR SOIC-8 | C7950 | 1 | OVLO | OC on nGATE
U6 | TL431 SOT-23 | C511218 | 1 | 2.495 V
Q1 | IRLR3110TRPBF DPAK | C152302 | 1 | 100 V logic-level | 9 thermal vias on tab
D1 | SS510 SMA | C8678 | 1 | Reverse | 100 V
D2 | SMBJ58A SMB | C13589 | 1 | TVS at J1 | not at the barrel
D3 | SS14 SOD-123 | C227409 | 1 | Buck catch | short SW node
Dz | MMSZ5226B | C212815 | 1 | ADC 3.3 V clamp
Dg | 1N4148W | C212147 | 1 | Fast gate dump
Dusb | 1N5819WS | C212814 | 1 | USB OR into 5 V
Elin | PESD1LIN | C841366 | 1 | LIN ESD
Drail | 0805 amber | C72043 | 1 | Rail
Darm | 0805 green | C72041 | 1 | Armed
L1 | 220 µH 6×6 ≥1 A | C167254 | 1 | Next to U2 SW
C1 | 10 µF 100 V 1210 | C59419 | 1 | VIN bulk at TVS
Cin | 100 nF 100 V 0805 | C1463 | 1 | VIN HF
C5v | 10 µF 16 V 0805 | C45783 | 2 | 5 V
C3v | 10 µF 10 V 0805 | C45783 | 2 | 3V3 + ESP
Clin | 220 pF 50 V | C14663 | 1 | ISO 17987
Cgate | 1 µF 25 V | C14663 | 1 | 80 ms-class ramp with 47 k
Ccomp | 10 nF 50 V | C14663 | 1 | XL7015 COMP
Csense | 1 nF 50 V | C14663 | 1 | ADC filter
Cen | 1 µF 16 V | C14663 | 1 | EN RC
Cesp | 100 nF 16 V | C14663 | 1 | ESP 3V3
R215 | 215 k 1 % | C17521 | 1 | OVLO top
R10ov | 10 k 1 % | C17414 | 1 | OVLO bot → 56.14 V
Rsns | 215 k 1 % | C17521 | 1 | ADC sense — 56 V → 2.49 V (100 k clips at Dz)
R10k | 10 k 1 % | C17414 | 1 | ADC
RfbH | 7.50 k 1 % | C17664 | 1 | 5.02 V with 2.49 k
RfbL | 2.49 k 1 % | C17636 | 1 | FB
R1k | 1 k | C17513 | 1 | GPIO5 series
R10g | 10 k | C17414 | 1 | nGATE pd
R47k | 47 k | C17710 | 1 | Gate ramp
Rtx | 10 k | C17414 | 1 | TXD high — do not omit
Rrx | 4.7 k | C17604 | 1 | RXD pull-up (open-drain)
Rlin | 1 k | C17513 | 1 | LIN series
Ren | 10 k | C17414 | 1 | EN
Rboot | 10 k | C17414 | 1 | BOOT
Ren5 | 100 k | C17407 | 1 | XL7015 EN to VIN
Rbias | 10 k | C17414 | 1 | TL431
Rcc1 | 5.1 k | C17610 | 2 | USB CC
Rr | 1 k | C17513 | 1 | Amber
Ra | 1 k | C17513 | 1 | Green
J1 | 3× Ø1.3 mm | — | 1 | VIN GND LIN | 18 AWG | pigtail to comb
J2 | PJ-002A 5.5×2.1 | C381065 | 1 | East | center +
J3 | USB-C 16P mid-mount | C165948 | 1 | South window

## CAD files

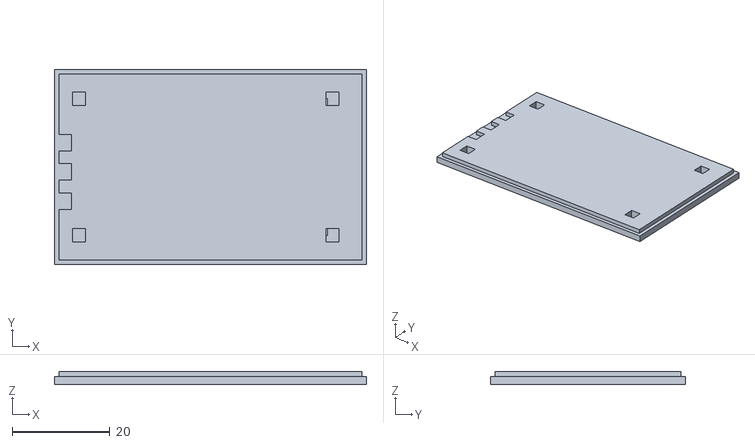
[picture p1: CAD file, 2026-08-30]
hardware/enclosure/padtap_lid.stl
64.0 x 40.0 x 2.65

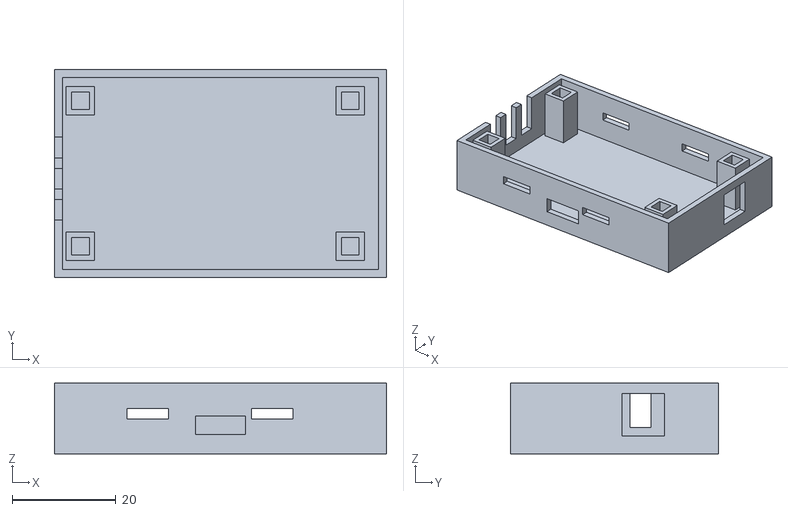
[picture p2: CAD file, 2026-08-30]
hardware/enclosure/padtap_base.stl
64.0 x 40.0 x 13.6

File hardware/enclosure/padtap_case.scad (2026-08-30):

// PadTap under-panel sled — sized to Rev A.1 (58 × 34 mm PCB)
// Units: millimetres. Print PETG, 0.2 mm layers, 4 perimeters, 30% gyroid.
//
//   openscad -o padtap_base.stl -D PART=\"base\" padtap_case.scad
//   openscad -o padtap_lid.stl  -D PART=\"lid\"  padtap_case.scad

PART = "base"; // "base" | "lid" | "preview"

outer_l = 64;
outer_w = 40;
base_h  = 13.6;
lid_t   = 1.6;
lip_h   = 1.2;
wall    = 1.5;
floor_t = 1.5;
corner  = 2.5;

inner_l = outer_l - 2 * wall;
inner_w = outer_w - 2 * wall;
inner_h = base_h - floor_t;

// PCB origin in this shell (wall + clearance)
board_ox = 2.0;
board_oy = 3.0;

// Cable comb (west) — lines up with J1 VIN / GND / LIN
comb_w      = 4.0;
comb_gap    = 6.0;
comb_saddle = 3.6;
comb_count  = 3;
comb_y0     = 11.0;

// Barrel (east) — PCB J2 at board (55.4, 22.5)
barrel_d = 8.2;
barrel_z = 6.0;
barrel_y = board_oy + 22.5;

// USB-C (south) — connector centre at board x = 30
usb_w = 9.6;
usb_h = 3.6;
usb_x = board_ox + 30 - usb_w / 2;
usb_z = 2.2;

// LED membranes over 0805s at board (51.35, 16.8) and (51.35, 14.4)
led_d  = 2.8;
led1_x = board_ox + 51.35;
led1_y = board_oy + 16.8;
led2_x = board_ox + 51.35;
led2_y = board_oy + 14.4;

// Vents
vent_w = 8;
vent_h = 2.0;
vent_z = 5.2;

// M2.5 at PCB holes (3,3) (55,3) (3,31) (55,31)
boss_d   = 5.5;
screw_d  = 2.7;
insert_d = 3.4;
insert_h = 3.8;
bosses   = [[board_ox + 3, board_oy + 3],
            [board_ox + 55, board_oy + 3],
            [board_ox + 3, board_oy + 31],
            [board_ox + 55, board_oy + 31]];

vhb = 10;

$fn = 48;

module round_rect(l, w, h, r) {
  hull() {
    for (x = [r, l - r])
      for (y = [r, w - r])
        translate([x, y, 0]) cylinder(h = h, r = r);
  }
}

module shell_body(h) {
  difference() {
    round_rect(outer_l, outer_w, h, corner);
    translate([wall, wall, -0.1])
      round_rect(inner_l, inner_w, h + 0.2, max(0.4, corner - wall));
  }
}

module cable_comb() {
  for (i = [0 : comb_count - 1]) {
    translate([-0.2, comb_y0 + i * comb_gap, floor_t + comb_saddle])
      cube([wall + 0.4, comb_w, inner_h + 1]);
  }
}

module barrel_hole() {
  translate([outer_l + 0.1, barrel_y, floor_t + barrel_z])
    rotate([0, -90, 0])
      cylinder(h = wall + 0.4, d = barrel_d);
}

module usb_slot() {
  translate([usb_x, -0.2, floor_t + usb_z])
    cube([usb_w, wall + 0.4, usb_h]);
}

module vents() {
  for (y = [-0.2, outer_w - wall - 0.2]) {
    for (x = [14, 38]) {
      translate([x, y, floor_t + vent_z])
        cube([vent_w, wall + 0.4, vent_h]);
    }
  }
}

module boss_set(h, hole_d, hole_h, z0) {
  for (p = bosses)
    translate([p[0], p[1], z0]) {
      difference() {
        cylinder(h = h, d = boss_d);
        translate([0, 0, -0.1])
          cylinder(h = hole_h + 0.2, d = hole_d);
      }
    }
}

module padtap_base() {
  difference() {
    union() {
      round_rect(outer_l, outer_w, floor_t, corner);
      shell_body(base_h);
      translate([wall / 2, wall / 2, base_h - lip_h])
        difference() {
          round_rect(outer_l - wall, outer_w - wall, lip_h, corner - wall / 2);
          translate([wall / 2, wall / 2, -0.1])
            round_rect(inner_l, inner_w, lip_h + 0.2, max(0.2, corner - wall));
        }
      boss_set(inner_h - 0.4, insert_d, insert_h, floor_t);
    }
    cable_comb();
    barrel_hole();
    usb_slot();
    vents();
  }
}

module padtap_lid() {
  difference() {
    union() {
      round_rect(outer_l, outer_w, lid_t, corner);
      translate([wall / 2 + 0.15, wall / 2 + 0.15, lid_t])
        round_rect(outer_l - wall - 0.3, outer_w - wall - 0.3, lip_h - 0.15, corner - wall / 2);
    }
    for (p = bosses)
      translate([p[0], p[1], -0.1])
        cylinder(h = lid_t + lip_h + 0.3, d = screw_d);
    for (p = bosses)
      translate([p[0], p[1], -0.01])
        cylinder(h = 0.9, d1 = 4.6, d2 = screw_d);
    for (p = [[led1_x, led1_y], [led2_x, led2_y]])
      translate([p[0], p[1], 0.4])
        cylinder(h = lid_t + lip_h, d = led_d);
    for (i = [0 : comb_count - 1])
      translate([-0.2, comb_y0 + i * comb_gap + 0.25, lid_t + 0.3])
        cube([wall + 2, comb_w - 0.5, lip_h]);
    for (x = [8, outer_l - 8 - vhb])
      for (y = [6, outer_w - 6 - vhb])
        translate([x, y, -0.01])
          cube([vhb, vhb, 0.35]);
  }
}

if (PART == "base") padtap_base();
else if (PART == "lid") padtap_lid();
else {
  padtap_base();
  translate([0, 0, base_h + 6]) padtap_lid();
}

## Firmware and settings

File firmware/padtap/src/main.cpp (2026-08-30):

#include <Arduino.h>
#include "lin_map.h"

// PadTap — Cybertruck WPC tap → Starlink Mini
// LIN is listen-only. Do not wire TLIN2029 TXD.
//
// Direct 48 V: switched raw Tesla rail.
//   Hardware LM393 + firmware latch kill the FET at 56.0 V.
//
// Tesla 48 V uses digital / solid-state fuses. They trip on capacitor
// inrush, not RMS. Do not slam a buck or the Mini's input caps onto
// the rail. VIN NTC (harness) + 80 ms FET ramp.

#ifndef PADTAP_DIRECT
#define PADTAP_DIRECT 1
#endif

static const int PIN_LIN_RX = 20;
static const int PIN_FET = 5;
static const int PIN_VIN_ADC = 4;
static const int PIN_LED_RAIL = 6;
static const int PIN_LED_ARM = 7;
static const int FET_PWM_CH = 1;

// 215 k / 10 k — same values as the LM393 divider. 56 V → 2.49 V at the pin,
// inside the C3's 11 dB range. 100 k / 10 k would put 48 V at 4.4 V: the zener
// clamps, the ADC saturates near 36 V, and this OVLO latch could never trip.
static const float VIN_DIV_TOP = 215000.0f;
static const float VIN_DIV_BOT = 10000.0f;
static const float VIN_RAIL_V = 30.0f;
static const float VIN_OVLO_V = 56.0f;
static const float VIN_OVLO_CLEAR_V = 54.0f;
static const uint32_t LIN_BAUD = 19200;
static const uint32_t RAMP_MS = 80;  // Mini Cin · dV/dt stays well under an e-fuse

enum Mode { MODE_AUTO, MODE_A, MODE_B, MODE_C };
static Mode mode = MODE_AUTO;

static bool sawVinDropOnToggle = false;
static bool sawLinToggle = false;
static bool lastLinEn = false;
static bool haveLin = false;
static bool arm = false;
static bool ovlatched = false;
static bool rampOn = false;
static uint32_t rampStartMs = 0;

static uint8_t linBuf[10];
static uint8_t linLen = 0;
static uint32_t linLastMs = 0;

float readVin() {
  // eFuse-calibrated millivolts — raw/4095*3.3 is off by up to ~10 % on the C3,
  // too coarse for a 56.0 V trip decision.
  const float vAdc = analogReadMilliVolts(PIN_VIN_ADC) / 1000.0f;
  return vAdc * ((VIN_DIV_TOP + VIN_DIV_BOT) / VIN_DIV_BOT);
}

bool linEnableBit(const uint8_t *data, uint8_t n) {
  if (LIN_ENABLE_PID == 0 || n <= LIN_ENABLE_BYTE) return lastLinEn;
  bool bit = (data[LIN_ENABLE_BYTE] & LIN_ENABLE_MASK) != 0;
  if (LIN_ENABLE_INVERT) bit = !bit;
  return bit;
}

void parseLinByte(uint8_t b) {
  uint32_t now = millis();
  if (now - linLastMs > 8) linLen = 0;
  linLastMs = now;
  // The break lands as a 0x00 with framing error before sync — drop leading
  // bytes until 0x55 so the PID always sits at linBuf[1].
  if (linLen == 0 && b != 0x55) return;
  if (linLen < sizeof(linBuf)) linBuf[linLen++] = b;

  if (linLen >= 3) {
    uint8_t pid = linBuf[1] & 0x3F;
    if (LIN_ENABLE_PID != 0 && pid == LIN_ENABLE_PID) {
      bool en = linEnableBit(&linBuf[2], linLen - 2);
      if (haveLin && en != lastLinEn) sawLinToggle = true;
      lastLinEn = en;
      haveLin = true;
    }
    if (linLen == 3) Serial.printf("LIN pid=0x%02X\n", pid);
  }
}

void applyMode(bool rail) {
  if (ovlatched) {
    arm = false;
    return;
  }
  if (mode == MODE_AUTO) {
    if (!rail) {
      arm = false;
      return;
    }
    if (sawVinDropOnToggle) mode = MODE_A;
    else if (sawLinToggle) mode = MODE_B;
  }
  if (mode == MODE_A) arm = rail;
  else if (mode == MODE_B) arm = rail && lastLinEn;
  else if (mode == MODE_C) arm = rail;
  else arm = rail && (haveLin ? lastLinEn : true);
}

void driveFet(bool want) {
  static bool lastWant = false;
  if (!want) {
    ledcWrite(FET_PWM_CH, 0);
    rampOn = false;
    lastWant = false;
    return;
  }
  if (!lastWant) {
    rampOn = true;
    rampStartMs = millis();
    Serial.println("FET ramp");
  }
  lastWant = true;
  if (rampOn) {
    uint32_t dt = millis() - rampStartMs;
    uint32_t duty = dt >= RAMP_MS ? 255 : (dt * 255UL) / RAMP_MS;
    ledcWrite(FET_PWM_CH, duty);
    if (duty >= 255) rampOn = false;
  } else {
    ledcWrite(FET_PWM_CH, 255);
  }
}

void setup() {
  ledcSetup(FET_PWM_CH, 20000, 8);
  ledcAttachPin(PIN_FET, FET_PWM_CH);
  ledcWrite(FET_PWM_CH, 0);
  pinMode(PIN_LED_RAIL, OUTPUT);
  pinMode(PIN_LED_ARM, OUTPUT);
  analogReadResolution(12);
  Serial.begin(115200);
  Serial1.begin(LIN_BAUD, SERIAL_8N1, PIN_LIN_RX, -1);  // LIN is 8N1, not 8E1
  delay(300);
  Serial.printf("PadTap boot  build=%s  mode=AUTO  LIN RX only  OVLO=%.0f V  ramp=%u ms\n",
                PADTAP_DIRECT ? "DIRECT48" : "BUCK36", VIN_OVLO_V, (unsigned)RAMP_MS);
}

void loop() {
  while (Serial1.available()) parseLinByte((uint8_t)Serial1.read());

  if (Serial.available()) {
    String cmd = Serial.readStringUntil('\n');
    cmd.trim();
    cmd.toLowerCase();
    if (cmd == "mode a") mode = MODE_A;
    if (cmd == "mode b") mode = MODE_B;
    if (cmd == "mode c") mode = MODE_C;
    if (cmd == "mode auto") mode = MODE_AUTO;
    if (cmd == "ov reset") ovlatched = false;
    Serial.printf("mode=%d ov=%d\n", (int)mode, ovlatched);
  }

  // Start false: on a USB bench boot vin reads 0, and a true seed would count
  // that as a rail drop and mis-latch AUTO into Mode A.
  static bool lastRail = false;
  float vin = readVin();
  bool rail = vin > VIN_RAIL_V;
  if (lastRail && !rail) sawVinDropOnToggle = true;
  lastRail = rail;

  if (vin >= VIN_OVLO_V) {
    if (!ovlatched) Serial.printf("OVLO trip vin=%.1f\n", vin);
    ovlatched = true;
  } else if (ovlatched && vin <= VIN_OVLO_CLEAR_V) {
    ovlatched = false;
    Serial.printf("OVLO clear vin=%.1f\n", vin);
  }

  applyMode(rail);
  if (ovlatched) arm = false;
  driveFet(arm);
  digitalWrite(PIN_LED_RAIL, rail ? HIGH : LOW);
  digitalWrite(PIN_LED_ARM, arm ? HIGH : LOW);

  static uint32_t t = 0;
  if (millis() - t > 1000) {
    t = millis();
    Serial.printf("vin=%.1f rail=%d arm=%d ramp=%d mode=%d lin=%d drop=%d ov=%d\n",
                  vin, rail, arm, rampOn, (int)mode, lastLinEn, sawVinDropOnToggle, ovlatched);
  }
}

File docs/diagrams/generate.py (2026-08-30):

#!/usr/bin/env python3
"""Generate PadTap README diagrams (dark Cybertruck sheet)."""
from pathlib import Path
import html

OUT = Path(__file__).parent
BG, PANEL, PANEL2 = "#0B0C0E", "#141518", "#1C1E22"
LINE, AMBER, TEXT = "#2A2D32", "#E8A317", "#E8EAED"
MUTED, STEEL, OK = "#8B9098", "#C5C8CE", "#7DAE74"
DANGER, BLUE = "#C45C4A", "#6AA6C9"
FONT = "ui-sans-serif, system-ui, -apple-system, sans-serif"
MONO = "ui-monospace, SFMono-Regular, Menlo, monospace"


def svg(w, h, body, title=""):
    return f'''<?xml version="1.0" encoding="UTF-8"?>
<svg xmlns="http://www.w3.org/2000/svg" width="{w}" height="{h}" viewBox="0 0 {w} {h}" role="img" aria-label="{title}">
<rect width="{w}" height="{h}" fill="{BG}"/>
{body}
</svg>
'''


def t(x, y, s, *, fill=TEXT, size=13, anchor="start", family=FONT, weight="500"):
    s = html.escape(s)
    return f'<text x="{x}" y="{y}" fill="{fill}" font-size="{size}" font-family="{family}" font-weight="{weight}" text-anchor="{anchor}">{s}</text>'


def r(x, y, w, h, *, fill=PANEL, stroke=LINE, rx=8, sw=1.5):
    return f'<rect x="{x}" y="{y}" width="{w}" height="{h}" rx="{rx}" fill="{fill}" stroke="{stroke}" stroke-width="{sw}"/>'


def line(x1, y1, x2, y2, *, stroke=AMBER, sw=2):
    return f'<line x1="{x1}" y1="{y1}" x2="{x2}" y2="{y2}" stroke="{stroke}" stroke-width="{sw}"/>'


def path(d, *, stroke=AMBER, fill="none", sw=2):
    return f'<path d="{d}" fill="{fill}" stroke="{stroke}" stroke-width="{sw}"/>'


def circ(x, y, rad, *, fill=PANEL, stroke=AMBER, sw=1.5):
    return f'<circle cx="{x}" cy="{y}" r="{rad}" fill="{fill}" stroke="{stroke}" stroke-width="{sw}"/>'


def cap(x, y, s, fill=MUTED):
    return t(x, y, s, fill=fill, size=11, family=MONO)


# ---------------------------------------------------------------------------
def system(direct=True):
    w, h = 920, 430
    board = "DIRECT 48 V" if direct else "BUCK 36 V"
    mid = "OVLO kills FET at 56 V" if direct else "58 V → 36 V buck"
    fet = "100 V FET + 3 A fuse" if direct else "MOSFET + 3 A fuse"
    mini = "44–50 V  ·  5.5 mm" if direct else "36 V  ·  5.5 mm"
    parts = [
        r(8, 70, 170, 220),
        t(93, 108, "Cybertruck", anchor="middle", fill=STEEL),
        t(93, 128, "console harness", anchor="middle", fill=MUTED, size=12),
        t(93, 168, "RD/BU  BN/BU", anchor="middle", fill=AMBER, size=12, family=MONO),
        t(93, 188, "GN LIN  P4", anchor="middle", fill=AMBER, size=12, family=MONO),
        t(93, 240, "X0648  12-way", anchor="middle", fill=MUTED, size=11),
        t(93, 258, "6098-5718", anchor="middle", fill=MUTED, size=11),
        line(178, 180, 250, 180),
        r(250, 90, 150, 180, fill=PANEL2, stroke=AMBER),
        t(325, 128, "Y-HARNESS", anchor="middle", fill=AMBER, size=14, family=MONO),
        t(325, 152, "12-way 1:1", anchor="middle", size=12),
        t(325, 170, "5718 + 6210", anchor="middle", size=12),
        t(325, 210, "tap 1 / 9 / 4", anchor="middle", fill=MUTED, size=11),
        line(400, 150, 470, 150, stroke=STEEL),
        path("M325 270 V320 H470"),
        r(470, 70, 170, 140),
        t(555, 112, "CHARGER 6210", anchor="middle", fill=STEEL),
        t(555, 136, "1877045 Qi+NFC", anchor="middle", fill=MUTED, size=12),
        t(555, 156, "PCB header", anchor="middle", fill=MUTED, size=12),
        r(470, 250, 170, 140, stroke=AMBER),
        t(555, 292, board, anchor="middle", fill=AMBER, size=14, family=MONO),
        t(555, 316, "LIN sniffer", anchor="middle", size=12),
        t(555, 334, mid, anchor="middle", size=12),
        t(555, 352, fet, anchor="middle", size=12),
        line(640, 320, 710, 320),
        r(710, 250, 190, 140),
        t(805, 300, "Starlink Mini", anchor="middle", fill=STEEL),
        t(805, 324, mini, anchor="middle", fill=AMBER, size=12, family=MONO),
        t(805, 344, "25–40 W avg · 60 W pk", anchor="middle", fill=MUTED, size=12),
        t(20, 28, "PADTAP  ·  SYSTEM" + ("  ·  DIRECT 48 V" if direct else "  ·  BUCK 36 V"),
          fill=AMBER, size=12, family=MONO),
    ]
    name = "system-direct.svg" if direct else "system-buck.svg"
    (OUT / name).write_text(svg(w, h, "\n".join(parts), f"PadTap system {board}"), encoding="utf-8")


def pin_map():
    used = {1, 3, 4, 9, 10, 11, 12}
    tap = {1, 4, 9}
    parts = [
        t(360, 22, "X0648  ·  6098-5718 FACE  ·  LATCH UP  ·  1–6 OVER 7–12", fill=AMBER, size=12, family=MONO, anchor="middle"),
        r(16, 40, 248, 200, fill=PANEL2, stroke=STEEL, rx=22, sw=2),
        r(100, 40, 76, 18, fill=PANEL, stroke=STEEL, rx=4),
        t(140, 54, "LATCH", fill=MUTED, size=10, family=MONO, anchor="middle"),
    ]
    for n in range(1, 13):
        col = (n - 1) % 6
        row = 0 if n <= 6 else 1
        x = 44 + col * 38
        y = 100 + row * 56
        on = n in used
        parts += [
            r(
                x - 14,
                y - 14,
                28,
                28,
                fill=AMBER if n in tap else (PANEL if on else PANEL2),
                stroke=AMBER if on else LINE,
                rx=3,
            ),
            t(
                x,
                y + 5,
                str(n),
                fill="#1A1303" if n in tap else (TEXT if on else MUTED),
                size=12,
                family=MONO,
                anchor="middle",
            ),
        ]
    rows = [
        ("1", "48 V+ HSD", "RD/BU 1.00  8240-0213  TAP"),
        ("3", "USB GND thru", "WH/BU 1.00  8240-0213  pass"),
        ("4", "LIN in", "GN 0.35  8240-0215  listen"),
        ("9", "WPC GND", "BN/BU 1.00  8240-0213  TAP"),
        ("10", "LIN out HVAC", "GY 0.35  8240-0215  never break"),
        ("11", "CANH", "PK/WH 0.35  8240-0215  no tap"),
        ("12", "CANL", "BU/WH 0.35  8240-0215  no tap"),
    ]
    y = 58
    parts.append(r(280, 40, 424, 200, fill=PANEL))
    for n, name, how in rows:
        parts += [
            t(300, y, n, fill=AMBER, size=13, family=MONO),
            t(328, y, name, fill=TEXT, size=13),
            t(300, y + 16, how, fill=MUTED, size=11, family=MONO),
        ]
        y += 26
    (OUT / "pin-map.svg").write_text(svg(720, 260, "\n".join(parts), "X0648 cavity map"), encoding="utf-8")
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

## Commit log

2026-08-30 PadTap: Y-harness, 36 V intercept board, LIN firmware, research and BOM
2026-08-30 Add harness, schematic, BOM, and ESP32-C3 firmware
    [bom.csv]
2026-08-30 Add under-panel PETG sled for the PadTap board.
    108 x 56 x 18 mm two-piece case with a west cable comb, east barrel,
    USB window, VHB lid, and low-profile 36 V buck so it tucks under a
    console panel. OpenSCAD is the print source; compact STLs included.
    [bom.csv, padtap_base.stl, padtap_case.scad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]
2026-08-30 Add Direct 48 V build: switched pass-through, 56 V OVLO, no buck.
    Starlink Mini teardown parts are 60 V-class; Tesla nominal 44–50 V
    is in range. Hardware LM393 + firmware latch open the FET at 56.0 V
    so Tesla’s 58 V peak never reaches the barrel. Buck 36 V remains the
    conservative env.
    [bom.csv]
2026-08-30 Add schematics, drawings, and enclosure renders to the README.
    Dark-sheet SVGs for system, Direct/Buck schematics, Y-harness, pin map,
    OVLO, GPIO, voltage, and the 108×56×18 mm sled, plus concept renders.
2026-08-30 Add NTC inrush limiter and 80 ms FET ramp for Tesla digital fuses.
    Cybertruck 48 V e-fuses trip on buck input-cap inrush, not RMS watts —
    the same failure as a raw converter on the frunk tap. 10 Ω ≥3 A ICL on
    VIN (harness, next to the fuses) plus a PWM ramp on the load FET so
    Starlink Mini’s caps don’t dump the pad circuit.
    [bom.csv]
2026-08-30 Replace hypothesized 4-pin map with Tesla C X0648 from sheet 46.
    Wireless Phone Charger + NFC Reader is a 12-way. 48 V is Right Controller
    HSD X0034-91 shared with USB; LIN daisy-chains pin 4 to HVAC on pin 10;
    CAN auth is 11/12. Tap 1, 9, 4 only. Do not republish Tesla’s PDF.
    [bom.csv]
2026-08-30 Lock the Y-harness to Sumitomo 6098-5718 / 6098-6210.
    Vehicle plug is the grey 12-way female (Tesla 1042593-03-A). Charger is
    the DL PCB header. Terminals 8240-0213 (1.00 mm²) and 8240-0215 (0.35).
    Do not crimp 16 AWG into 0213. 6210 is through-hole — solder a pigtail.
    [bom.csv]
2026-08-30 Add Tesla X0648 cavity map: latch up, 1–6 over 7–12.
    Redrawn from the connector page. Tap 1, 9, 4. Empty 2, 5–8.
    Do not republish Tesla artwork.
2026-08-30 Redraw every diagram on 6098-5718 / 6098-6210.
    Y is wire-to-board: vehicle 5718 onto our 6210 header, our 5718 into
    the charger. Cavity map latch-up 1–6 over 7–12. FET is IRL540NPBF.
    Fuses are 58 V MINI. Shop list with buy links. Concept connector renders.
    [bom.csv]
2026-08-30 Drop concept renders. Rewrite the README around the real drawings.
    Pin map, Y-harness, Direct schematic, enclosure section. Buy list and
    install in one pass. No fake product shots.
2026-08-30 Add PadTap Rev A: 104.8×52.8 mm 2-layer layout and JLCPCB gerbers.
    Board drops into the sled. West harness pads, east barrel, south USB-C.
    IRLR3110 DPAK, TLIN TXD not wired. Drawing lives on the README.
    [PadTap-RevA-NPTH.DRL, PadTap-RevA-PTH.DRL, PadTap-RevA.GBL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]
2026-08-30 Rev A.1: 58×34 mm board, 48 V island, short SW node, FET thermal vias.
    TXD pulled high (internal pulldown would dominate LIN). OVLO kept off
    the switch node. USB and barrel still hit the sled walls.
    [PadTap-RevA-NPTH.DRL, PadTap-RevA-PTH.DRL, PadTap-RevA.GBL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]
2026-08-30 Shrink sled to 64×40×15 mm around the Rev A.1 board.
    Comb, barrel, USB-C, and LED membranes line up with the 58×34 mm PCB.
    Bosses match the four M2.5 holes. 15 mm drop under the panel.
    [bom.csv, padtap_base.stl, padtap_case.scad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]
2026-08-30 Deprecate the 36 V buck path. Direct 48 V is the product.
    Sled is 15 mm and cannot fit a 36 V module. Remove firmware env:buck.
    Keep hardware/schematic.md as an archive.
2026-08-30 Fix blind firmware OVLO, LM393 pinout, LIN framing.
    - VSENSE divider 100k/10k -> 215k/10k: 48 V put 4.4 V on GPIO4, the
    3.3 V zener clamped it, and the ADC saturated near 36 V - the
    firmware 56.0 V latch could never trip. 56 V now reads 2.49 V.
    Updated firmware, schematics, BOMs, diagrams, and Rev A.1 board
    (Rsns 215 k, C17521); regenerated gerbers.
    - LM393 U5 pins were rotated (IN- on OUT1, OUT on IN1+); mapped
    1 OUT1 / 2 IN1- / 3 IN1+ and rerouted nGATE, 1IN-, VREF.
    - LIN UART 8E1 -> 8N1; resync on the 0x55 sync byte so a leading
    break 0x00 no longer shifts the PID; log once per frame.
    - readVin uses eFuse-calibrated analogReadMilliVolts.
    - Seed lastRail false so a USB bench bo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
    [bom-jlc.csv, bom.csv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]
2026-08-30 Add VIN sense divider and gate network to the README board list.
    Claude-Session: https://claude.ai/code/session_012zLgoD3WQrpG39JybXbGvW
